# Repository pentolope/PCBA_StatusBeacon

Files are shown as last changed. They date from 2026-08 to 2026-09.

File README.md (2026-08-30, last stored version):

# Status Beacon Controller

A small USB-powered status beacon board: a microcontroller, one pushbutton, at least eight individually controllable RGB LEDs, and a small programming/debug connector.

`PCBA_StatusBeacon` is the benchmark's Status Beacon Controller: a small, USB-powered board carrying a microcontroller, one pushbutton, at least eight individually controllable RGB LEDs, and a small programming/debug connector. The brief fixes the function, the power source, the single pushbutton, a floor of at least eight individually controllable RGB LEDs, the exposure of a small programming/debug connector, and the qualitative goals of being inexpensive and easy to assemble; it also states a preference for a two-layer board unless there is a compelling reason not to. Everything else is deliberately unfixed — the brief explicitly hands the MCU, the LED technology, the exact board shape, and the connector family to the design agent, and it names no form for either connector. This is a detail-1 brief, so nearly all architecture, part selection, rail design, mechanical definition and stackup detail are left to the design agent, and this repository intentionally records those as open decisions rather than pre-answering them.

> **This board has not been designed.** There is no schematic, no layout and no
> part selection here — only the brief, a reading of the brief, and the
> scaffolding a design run needs. That is the intended state of this repository,
> not a gap in it.

## What the brief fixes, and what it leaves open

The brief pins down 13 requirements and deliberately leaves
16 decisions to whoever designs the board. The `Source` column says
which is which: `brief` is quoted from [BRIEF.md](BRIEF.md), `metadata` comes
from the benchmark catalogue, and `open` means the brief does not fix it.

| Aspect | Value | Source |
|---|---|---|
| Category | simple-digital | metadata |
| Difficulty | 1 of 5 | metadata |
| Brief detail | 1 of 5 (low-detail brief; most architecture left open) | metadata |
| Likely layer count | 2 | metadata |
| Primary stressors | basic component selection, simple placement/routing, LED current limiting, connector access | metadata |
| Function and power source | A small USB-powered status beacon board | brief |
| Controller | A microcontroller (specific device not named by the brief) | brief |
| User input | One pushbutton | brief |
| Indicators | At least eight individually controllable RGB LEDs (a floor, with no upper bound stated) | brief |
| Programming/debug access | A small programming/debug connector must be exposed; the brief names no family, form or pinout | brief |
| Cost and assembly posture | Inexpensive and easy to assemble | brief |
| Layer count preference | Two layers preferred, deviation allowed only with a compelling reason | brief |
| MCU, LED technology, board shape, connector family | Explicitly delegated to the design agent by the brief | brief |
| Status of stated requirements | Stated requirements are authoritative; open choices are to be decided and documented, not invented into requirements | brief |
| Rails, regulation, and power budget | Not fixed by the brief — design agent's choice | open |

The full split, with the verbatim brief text substantiating every fixed
requirement, is in [board/requirements.md](board/requirements.md) and
machine-readably in [board/requirements.json](board/requirements.json).

**Missing details are design freedom, not permission to fabricate unstated user
requirements.** A choice the brief left open is recorded as a decision, with its
reasoning — never promoted into a requirement.

## Benchmark position

| | |
|---|---|
| Benchmark id | 1 of 32 |
| Category | simple-digital |
| Difficulty | 1 / 5 |
| Brief detail | 1 / 5 |
| Likely layer count | 2 |
| Primary stressors | basic component selection, simple placement/routing, LED current limiting, connector access |

At difficulty 1/5 and detail 1/5 in the `simple-digital` category, this board tests whether a design agent can execute competently with almost no specification handed to it — the metadata's stressors are basic component selection, simple placement/routing, LED current limiting, and connector access. The interesting question is not whether the circuit is hard, but whether the agent makes and justifies its own choices (MCU, LED technology, shape, connector family) instead of fabricating requirements the brief never stated. Two of those stressors — LED current limiting and connector access — are where the missing detail bites hardest: with no brightness, current, environment or mechanical context stated, the per-LED current, the total the board draws from USB with the whole array lit, and the physical usability of the connectors all have to be derived and shown rather than asserted.

This repository is one of thirty-two. The suite, the protocol and the results
live in [PCBA_AutoDesignAndTest_Bench](https://github.com/pentolope/PCBA_AutoDesignAndTest_Bench).

## Repository layout

| Path | Contents |
|---|---|
| `BRIEF.md` | the supplied brief — authoritative, preserved byte for byte, never edited |
| `board/requirements.md` | what the brief fixes, what it leaves open, and where decisions get recorded |
| `board/requirements.json` | the same split, machine-readable, each fixed requirement bound to brief text |
| `board/manifest.template.json` | the toolkit's minimum manifest, pre-filled for this board |
| `board/toolchain.json` | where this board's build finds KiCad and the router |
| `benchmark/metadata.json` | the supplied catalogue entry — category, difficulty, detail, stressors |
| `docs/architecture.md` | the decisions this board must make, as questions, unanswered |
| `docs/sources.md` | the classes of evidence the design will have to cite |
| `docs/status.md` | what exists, what does not, and what is deliberately absent |
| `candidates/` | disposable search output, ignored by Git |
| `.claude/skills/` | the accountability-review skill [CLAUDE.md](CLAUDE.md) requires before a push |
| `tooling/PCBA_AutoDesignAndTest` | the shared verification/routing/release toolkit, as a pinned submodule |

## Getting the repository

The toolkit is a submodule and carries KiCad Routing Tools as a submodule of its
own, so clone recursively:

```bash
git clone --recursive https://github.com/pentolope/PCBA_StatusBeacon.git
```

```bash
git submodule update --init --recursive
```

## Designing the board

Generic verification, routing and release logic is **not** written here. It is
consumed from `tooling/PCBA_AutoDesignAndTest`, which is board-agnostic by
construction and must stay that way; this repository owns the board and nothing
else. Start from
[the toolkit's onboarding guide](tooling/PCBA_AutoDesignAndTest/examples/onboarding.md),
and see [CLAUDE.md](CLAUDE.md) for the rules a design run works under.

```bash
python3 tooling/PCBA_AutoDesignAndTest/run.py preflight
```

## Brief integrity

`BRIEF.md` SHA-256 `57889bbb86eda40bff9fa7fda22a93a18370e8318bfdb673a84f301cc4c06788`

Every quotation in `board/requirements.json` is bound to those exact bytes. If
the brief ever changes, the bindings are stale by construction — which is the
point of recording the digest.

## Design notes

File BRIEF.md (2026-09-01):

# PCBA_StatusBeacon — Status Beacon Controller
## Design brief

Design a small USB-powered status beacon board with a microcontroller, one pushbutton, and at least eight individually controllable RGB LEDs. It should be inexpensive, easy to assemble, and expose a small programming/debug connector. Choose the MCU, LED technology, exact board shape, and connector family yourself. Prefer a two-layer board unless there is a compelling reason not to.

## Functional requirements

- Each LED's red, green and blue elements shall be settable independently, and updating one LED shall not disturb the others.
- The pushbutton shall be the only user control; press and release shall reach the MCU as single debounced events.
- On USB power alone, with no host software, the board shall reach a defined LED state.

## LED array and drive

- Drive signals shall meet the receiving device's input thresholds across the operating range, including any rail difference.
- Peak LED current shall be bounded by the drive circuit or by one documented firmware limit, shall repeat across assemblies without rework, and shall not produce visible flicker.

## Power and current budget

- Worst-case current, all LEDs at maximum with the MCU active, shall be calculated, measured at bring-up, and within what the board may draw from the port it declares.
- Operation shall hold over the full VBUS range the connector and cable permit at that load, with input capacitance inside the USB inrush limit and any lower rail within its temperature limits.

## Interfaces and debug connector

- The USB receptacle shall be mechanically retained so mating forces are not carried by signal joints alone; a Type-C sink shall present its class's CC terminations.
- The debug connector shall program and halt the chosen MCU in circuit on a blank or bricked device, be polarised or pin-1 marked, and be unnecessary in normal use.

## Mechanical, placement and assembly

- Two copper layers unless a documented constraint forces more, with continuous ground reference under the MCU and LED clock and data routing.
- LED positions shall form a deliberate, repeatable arrangement, and the button shall be operable without touching the LEDs or connector.
- Assembly shall need no more than stencil print, single-side placement and one reflow pass.

## Protection and bring-up

- Exposed USB contacts and the pushbutton shall have ESD protection to board ground; hot-plug shall not damage or latch up the board, and no signal shall be driven into an unpowered device.
- VBUS, ground and every LED drive signal shall be probeable when assembled, and total supply current measurable without cutting a trace.

## Open choices

- MCU, LED technology and drive topology, and per-channel resolution: on/off, or a stated modulation depth.
- USB receptacle and debug connector families; board outline and LED geometry; whether the board enumerates or takes power only.

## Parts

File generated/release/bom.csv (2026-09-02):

Quantity | Designator | Comment | Footprint | LCSC Part #
2 | C1,C17 | 4.7uF | Capacitor_SMD:C_0805_2012Metric | C1779
15 | C2,C3,C4,C5,C6,C7,C8,C9,C10,C11,C12,C13,C14,C15,C16 | 100nF | Capacitor_SMD:C_0402_1005Metric | C1525
12 | D1,D2,D3,D4,D5,D6,D7,D8,D9,D10,D11,D12 | WS2812B-V5/W | LED_SMD:LED_WS2812B_PLCC4_5.0x5.0mm_P3.2mm | C2874885
4 | D13,D14,D15,D16 | TPD1E10B06DPYR | StatusBeacon:TI_X1SON-2_1.0x0.6mm_P0.65mm | C48260
1 | J1 | USB_C_16P | StatusBeacon:USB_C_Receptacle_HRO_TYPE-C-31-M-12_LCSC | C165948
2 | R1,R2 | 5.1k | Resistor_SMD:R_0402_1005Metric | C25905
1 | R4 | 33R | Resistor_SMD:R_0402_1005Metric | C25105
1 | R5 | 1k | Resistor_SMD:R_0402_1005Metric | C11702
1 | R6 | 10k | Resistor_SMD:R_0402_1005Metric | C25744
1 | SW1 | K2-1187SQ-A4SW-06 | Button_Switch_SMD:SW_SPST_SKQG_WithoutStem | C92584
1 | U1 | PY32F003F18P6TU | Package_SO:TSSOP-20_4.4x6.5mm_P0.65mm | C5379864
1 | U2 | ME6211C50M5G-N | Package_TO_SOT_SMD:SOT-23-5 | C236670

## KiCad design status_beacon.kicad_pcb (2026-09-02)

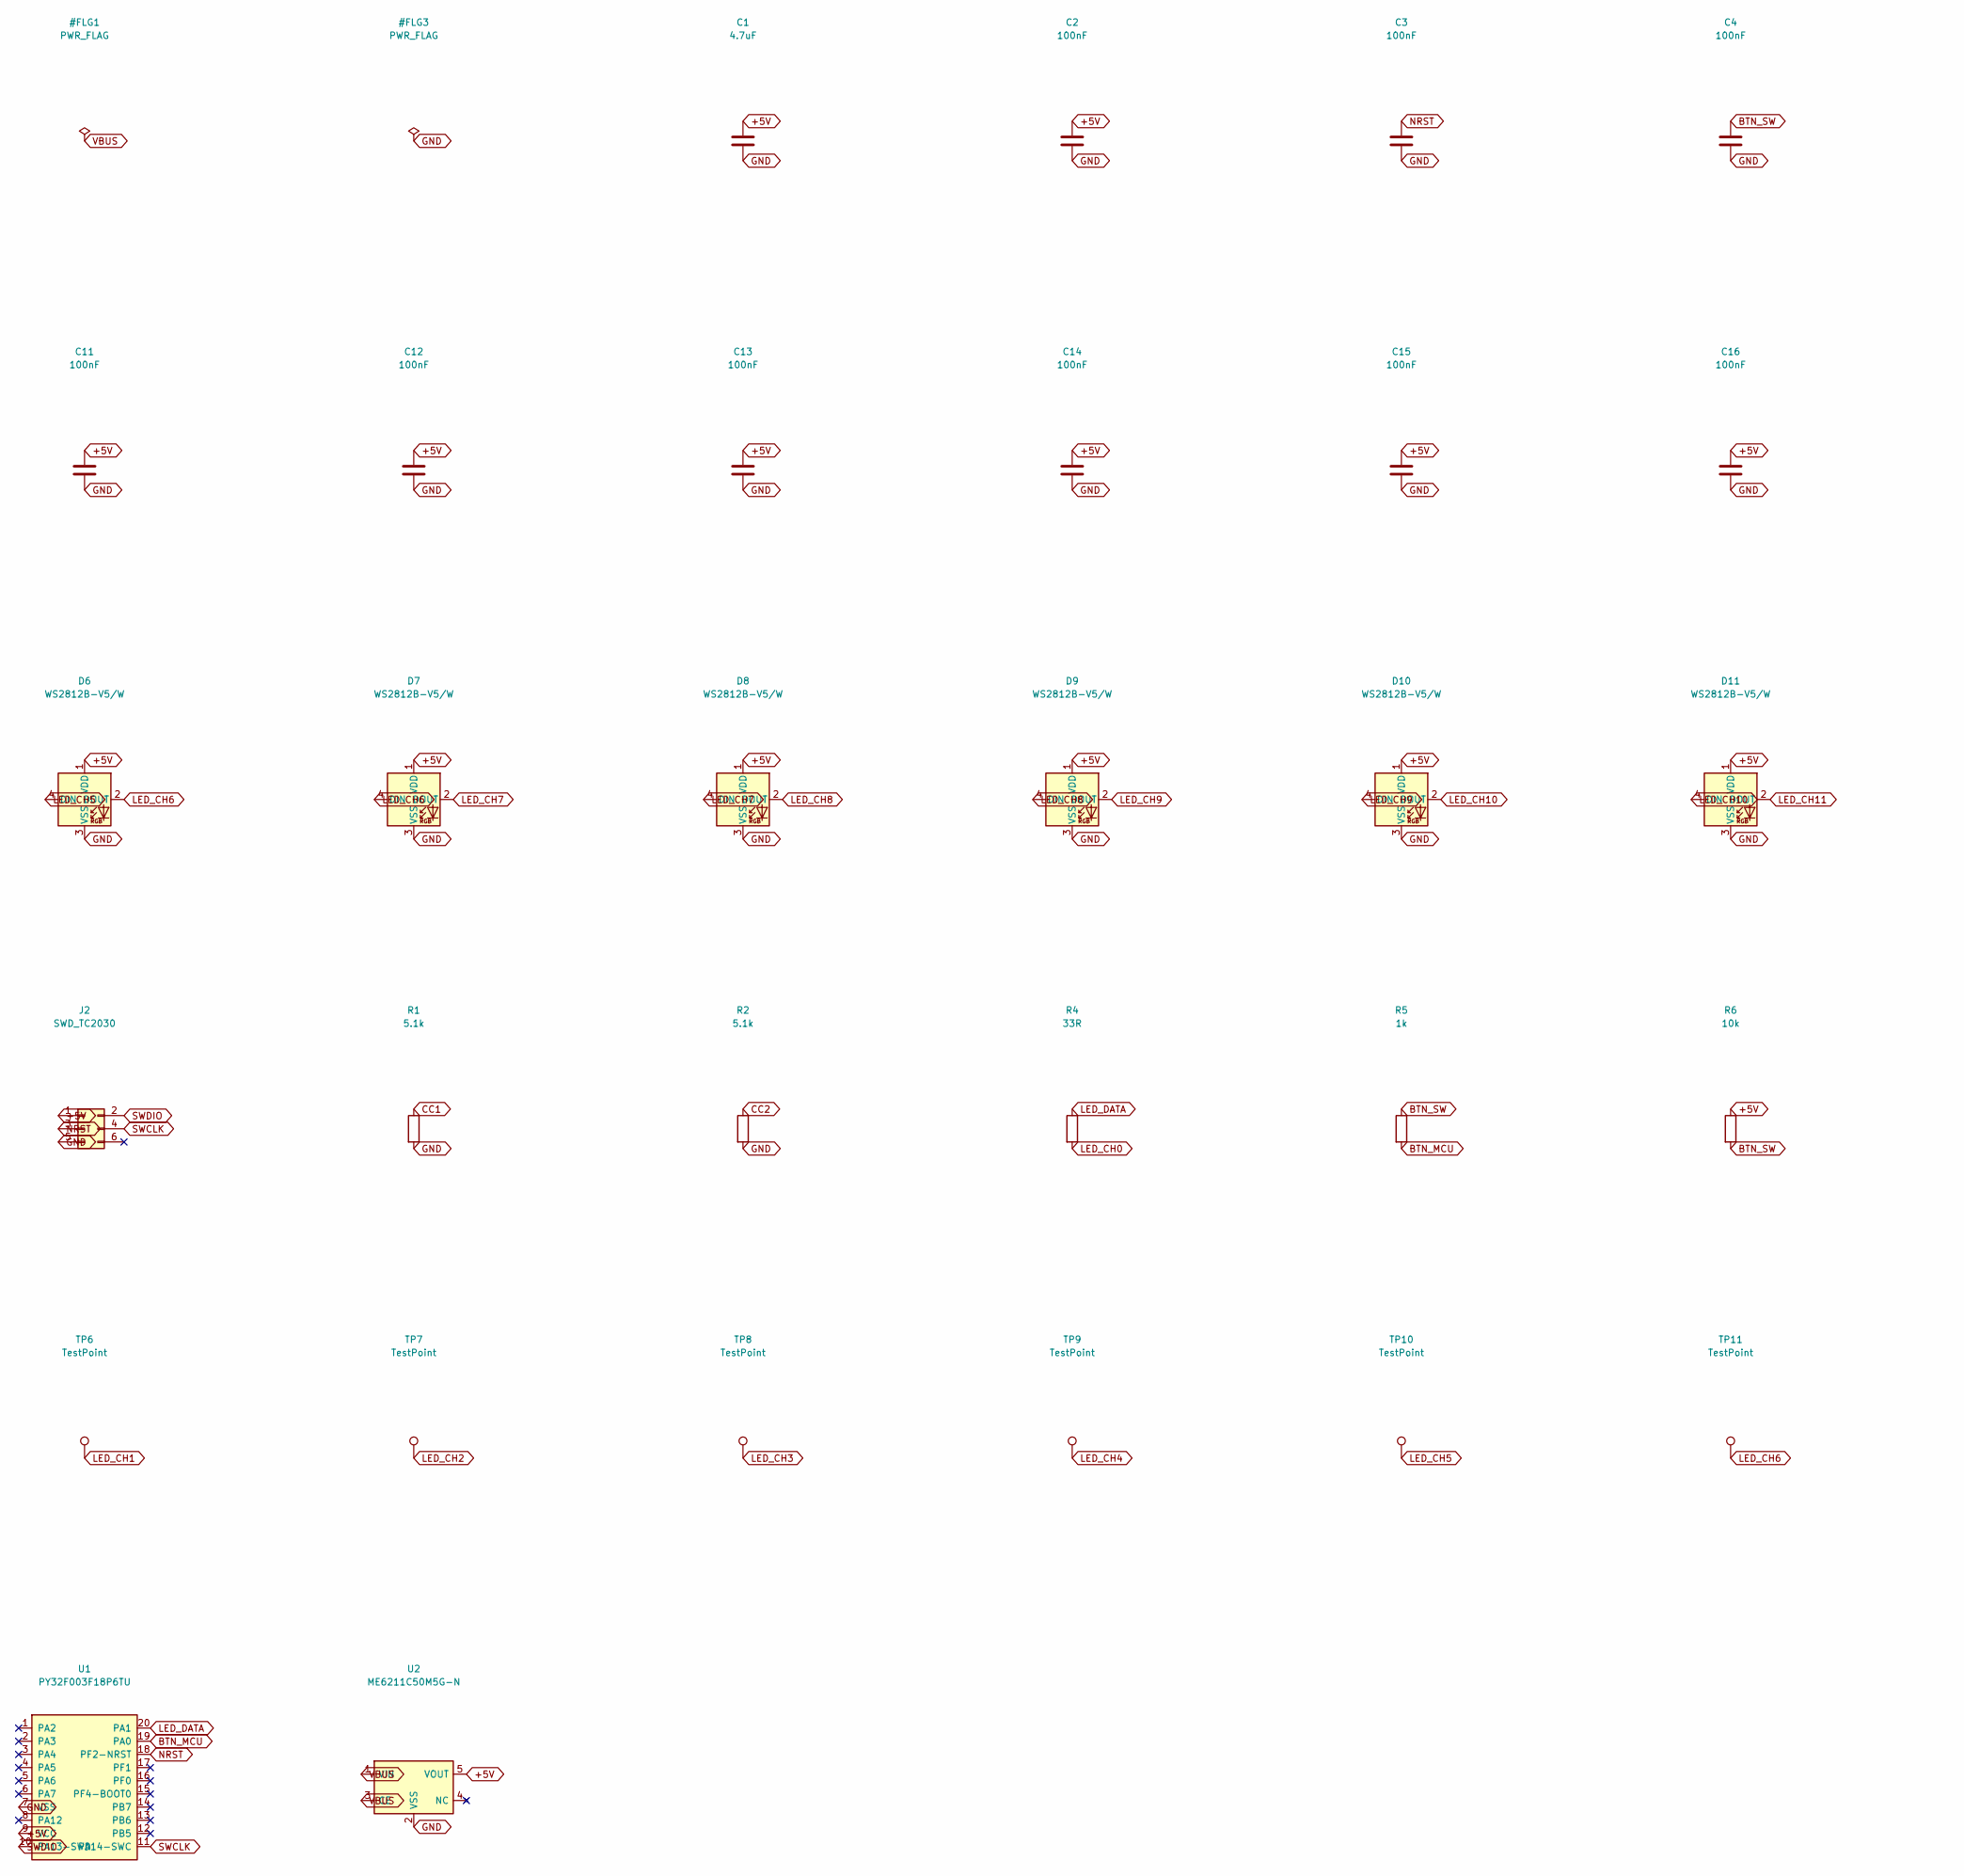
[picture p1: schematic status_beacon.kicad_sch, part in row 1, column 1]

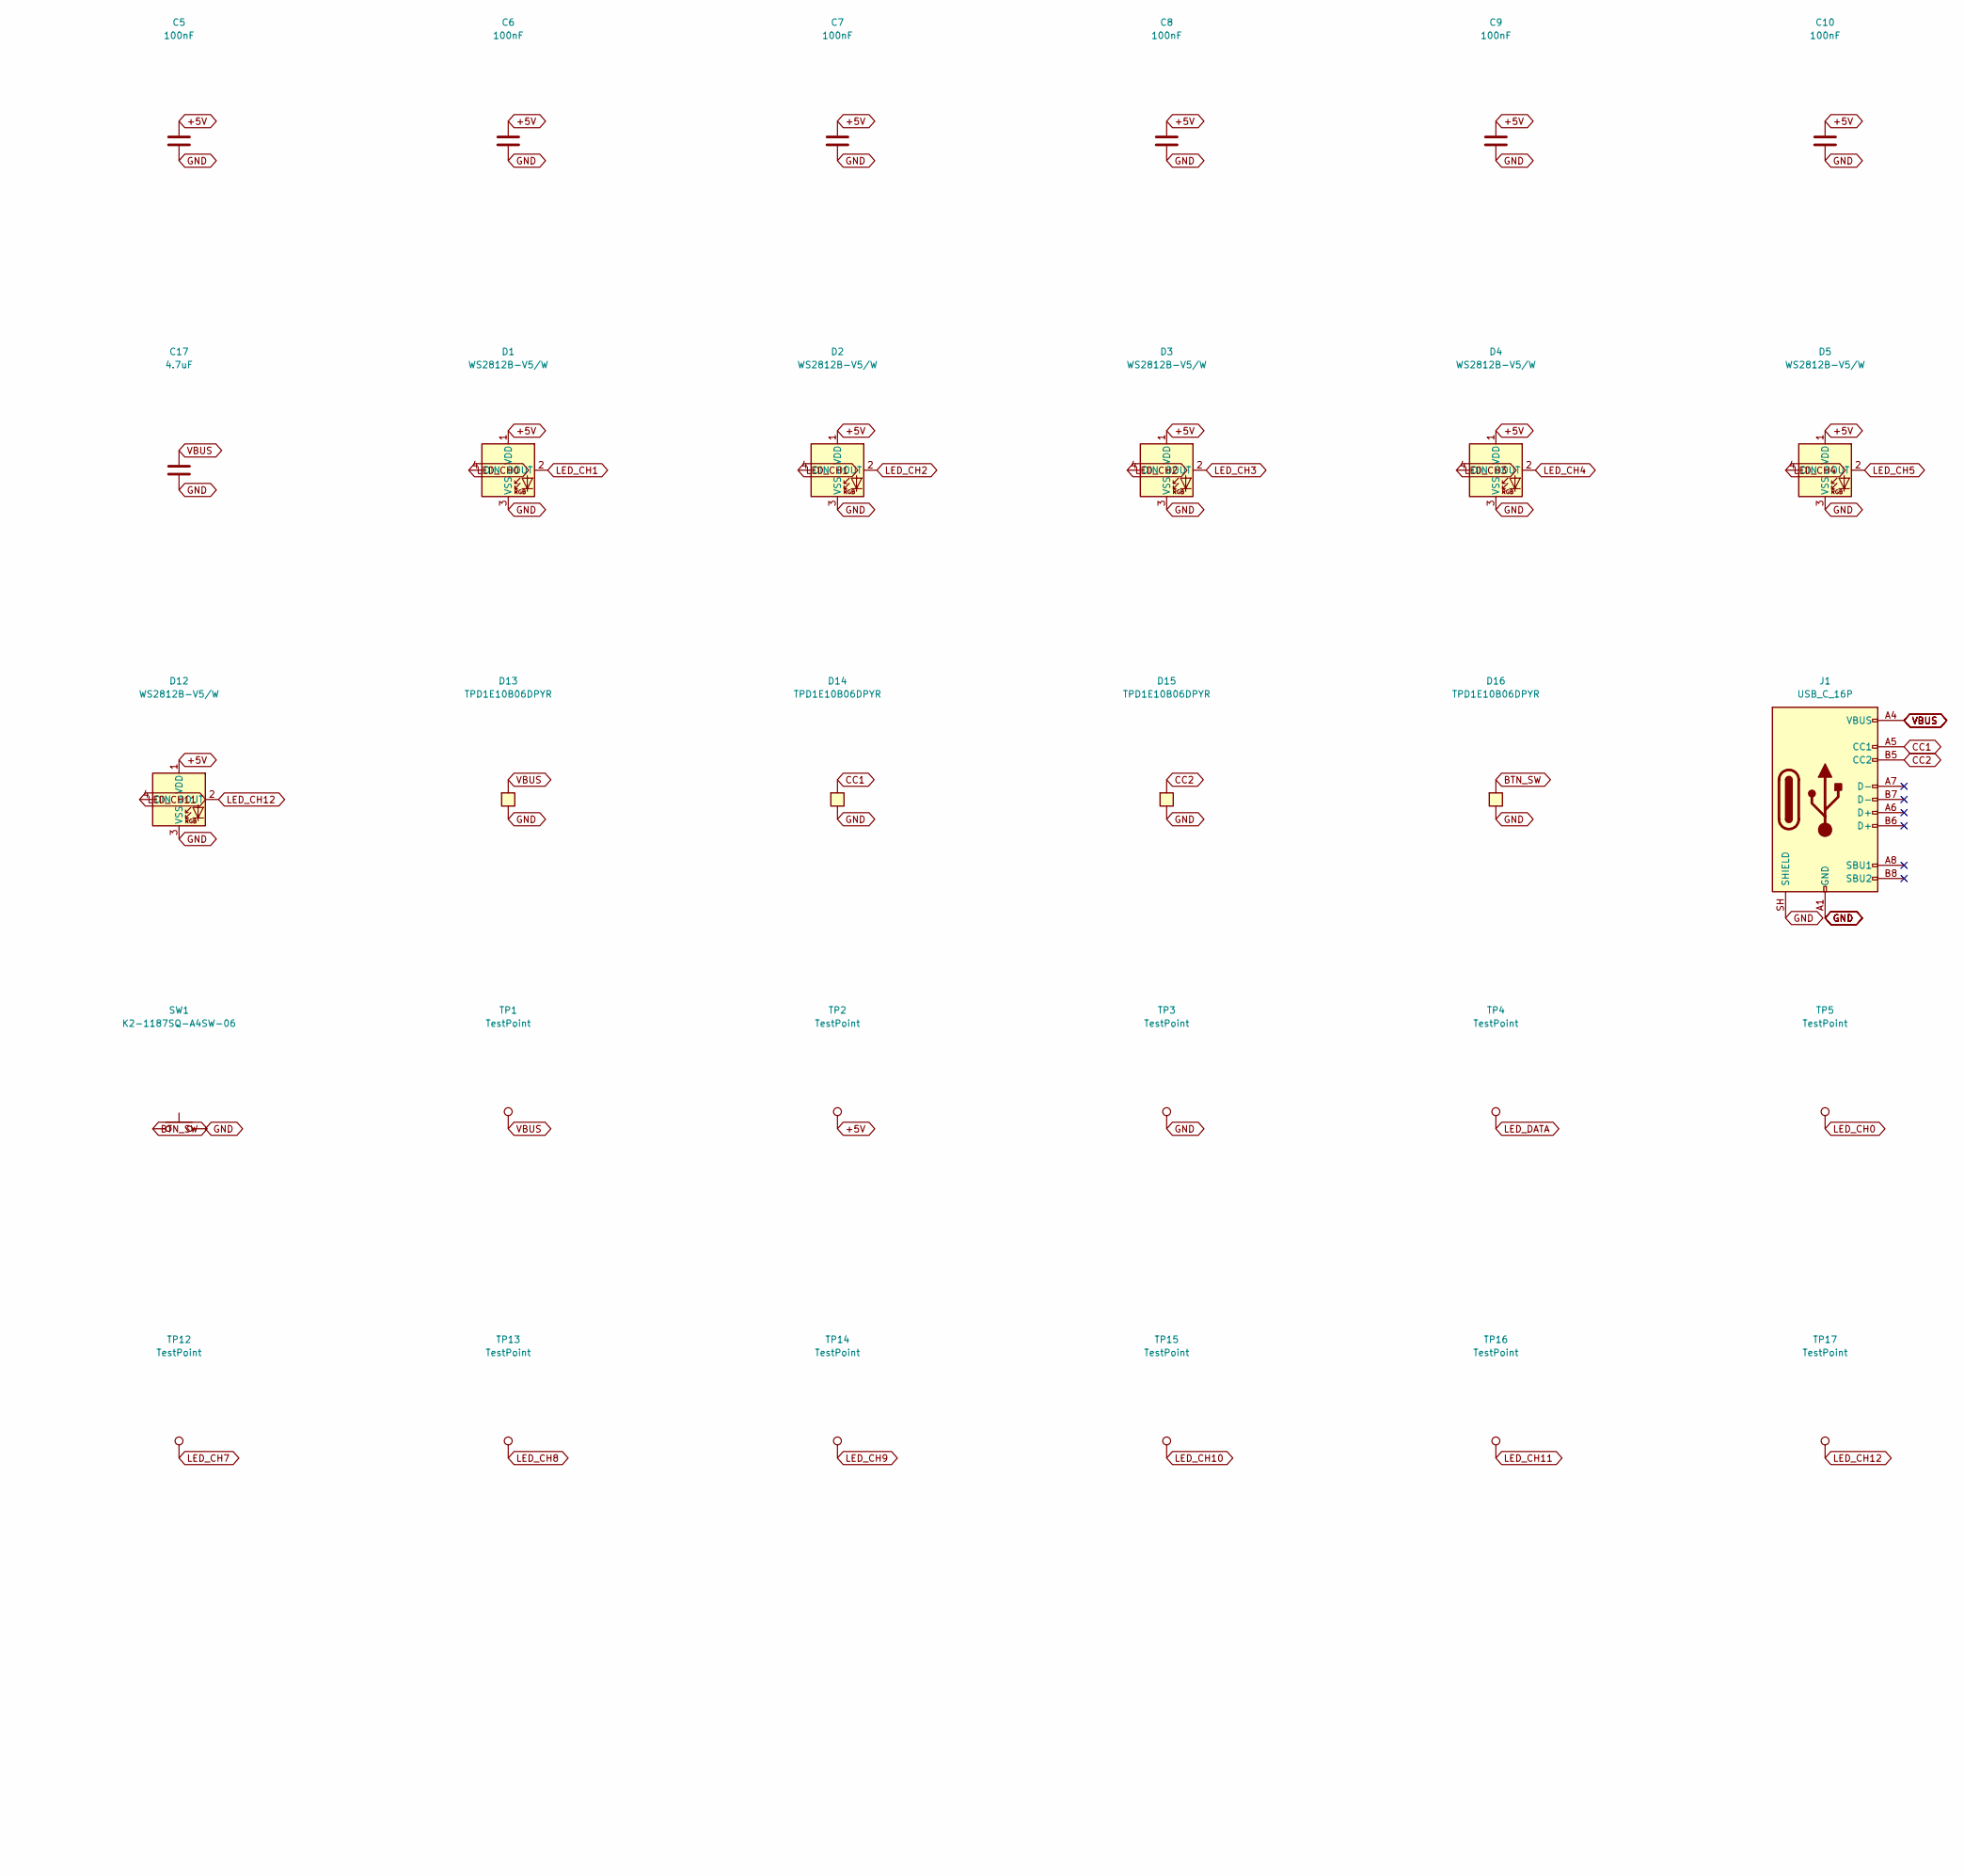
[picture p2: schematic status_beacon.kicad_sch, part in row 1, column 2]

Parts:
C1, C17: 4.7uF; C_0805_2012Metric; LCSC C1779
C2, C3, C4, C5, C6, C7, C8, C9, C10, C11, C12, C13, C14, C15, C16: 100nF; C_0402_1005Metric; LCSC C1525
D1, D2, D3, D4, D5, D6, D7, D8, D9, D10, D11, D12: WS2812B-V5/W; LED_WS2812B_PLCC4_5.0x5.0mm_P3.2mm; MPN WS2812B-V5/W; LCSC C2874885
D13, D14, D15, D16: TPD1E10B06DPYR; TI_X1SON-2_1.0x0.6mm_P0.65mm; MPN TPD1E10B06DPYR; LCSC C48260
J1: USB_C_16P; USB_C_Receptacle_HRO_TYPE-C-31-M-12_LCSC; MPN TYPE-C-31-M-12; LCSC C165948
J2: SWD_TC2030; Tag-Connect_TC2030-IDC-NL_2x03_P1.27mm_Vertical
R1, R2: 5.1k; R_0402_1005Metric; LCSC C25905
R4: 33R; R_0402_1005Metric; LCSC C25105
R5: 1k; R_0402_1005Metric; LCSC C11702
R6: 10k; R_0402_1005Metric; LCSC C25744
SW1: K2-1187SQ-A4SW-06; SW_SPST_SKQG_WithoutStem; MPN K2-1187SQ-A4SW-06; LCSC C92584
TP1, TP2, TP3, TP4, TP5, TP6, TP7, TP8, TP9, TP10, TP11, TP12, TP13, TP14, TP15, TP16, TP17: TestPoint; TestPoint_Pad_D1.0mm
U1: PY32F003F18P6TU; TSSOP-20_4.4x6.5mm_P0.65mm; MPN PY32F003F18P6TU; LCSC C5379864
U2: ME6211C50M5G-N; SOT-23-5; MPN ME6211C50M5G-N; LCSC C236670

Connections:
+5V: C1.1, C2.1, C5.1, C6.1, C7.1, C8.1, C9.1, C10.1, C11.1, C12.1, C13.1, C14.1, C15.1, C16.1, D1.1 (VDD), D2.1 (VDD), D3.1 (VDD), D4.1 (VDD), D5.1 (VDD), D6.1 (VDD), D7.1 (VDD), D8.1 (VDD), D9.1 (VDD), D10.1 (VDD), D11.1 (VDD), D12.1 (VDD), J2.1, R6.1, TP2.1, U1.9 (VCC), U2.5 (VOUT)
BTN_MCU: R5.2, U1.19 (PA0)
BTN_SW: C4.1, D16.2 (A2), R5.1, R6.2, SW1.1
CC1: D14.2 (A2), J1.A5 (CC1), R1.1
CC2: D15.2 (A2), J1.B5 (CC2), R2.1
GND: C1.2, C2.2, C3.2, C4.2, C5.2, C6.2, C7.2, C8.2, C9.2, C10.2, C11.2, C12.2, C13.2, C14.2, C15.2, C16.2, C17.2, D1.3 (VSS), D2.3 (VSS), D3.3 (VSS), D4.3 (VSS), D5.3 (VSS), D6.3 (VSS), D7.3 (VSS), D8.3 (VSS), D9.3 (VSS), D10.3 (VSS), D11.3 (VSS), D12.3 (VSS), D13.1 (A1), D14.1 (A1), D15.1 (A1), D16.1 (A1), J1.A1 (GND), J1.A12 (GND), J1.B1 (GND), J1.B12 (GND), J1.SH (SHIELD), J2.5, R1.2, R2.2, SW1.2, TP3.1, U1.7 (VSS), U2.2 (VSS)
LED_CH0: D1.4 (DIN), R4.2, TP5.1
LED_CH1: D1.2 (DOUT), D2.4 (DIN), TP6.1
LED_CH2: D2.2 (DOUT), D3.4 (DIN), TP7.1
LED_CH3: D3.2 (DOUT), D4.4 (DIN), TP8.1
LED_CH4: D4.2 (DOUT), D5.4 (DIN), TP9.1
LED_CH5: D5.2 (DOUT), D6.4 (DIN), TP10.1
LED_CH6: D6.2 (DOUT), D7.4 (DIN), TP11.1
LED_CH7: D7.2 (DOUT), D8.4 (DIN), TP12.1
LED_CH8: D8.2 (DOUT), D9.4 (DIN), TP13.1
LED_CH9: D9.2 (DOUT), D10.4 (DIN), TP14.1
LED_CH10: D10.2 (DOUT), D11.4 (DIN), TP15.1
LED_CH11: D11.2 (DOUT), D12.4 (DIN), TP16.1
LED_CH12: D12.2 (DOUT), TP17.1
LED_DATA: R4.1, TP4.1, U1.20 (PA1)
NRST: C3.1, J2.3, U1.18 (PF2-NRST)
SWCLK: J2.4, U1.11 (PA14-SWC)
SWDIO: J2.2, U1.10 (PA13-SWD)
VBUS: C17.1, D13.2 (A2), J1.A4 (VBUS), J1.A9 (VBUS), J1.B4 (VBUS), J1.B9 (VBUS), TP1.1, U2.1 (VIN), U2.3 (CE)

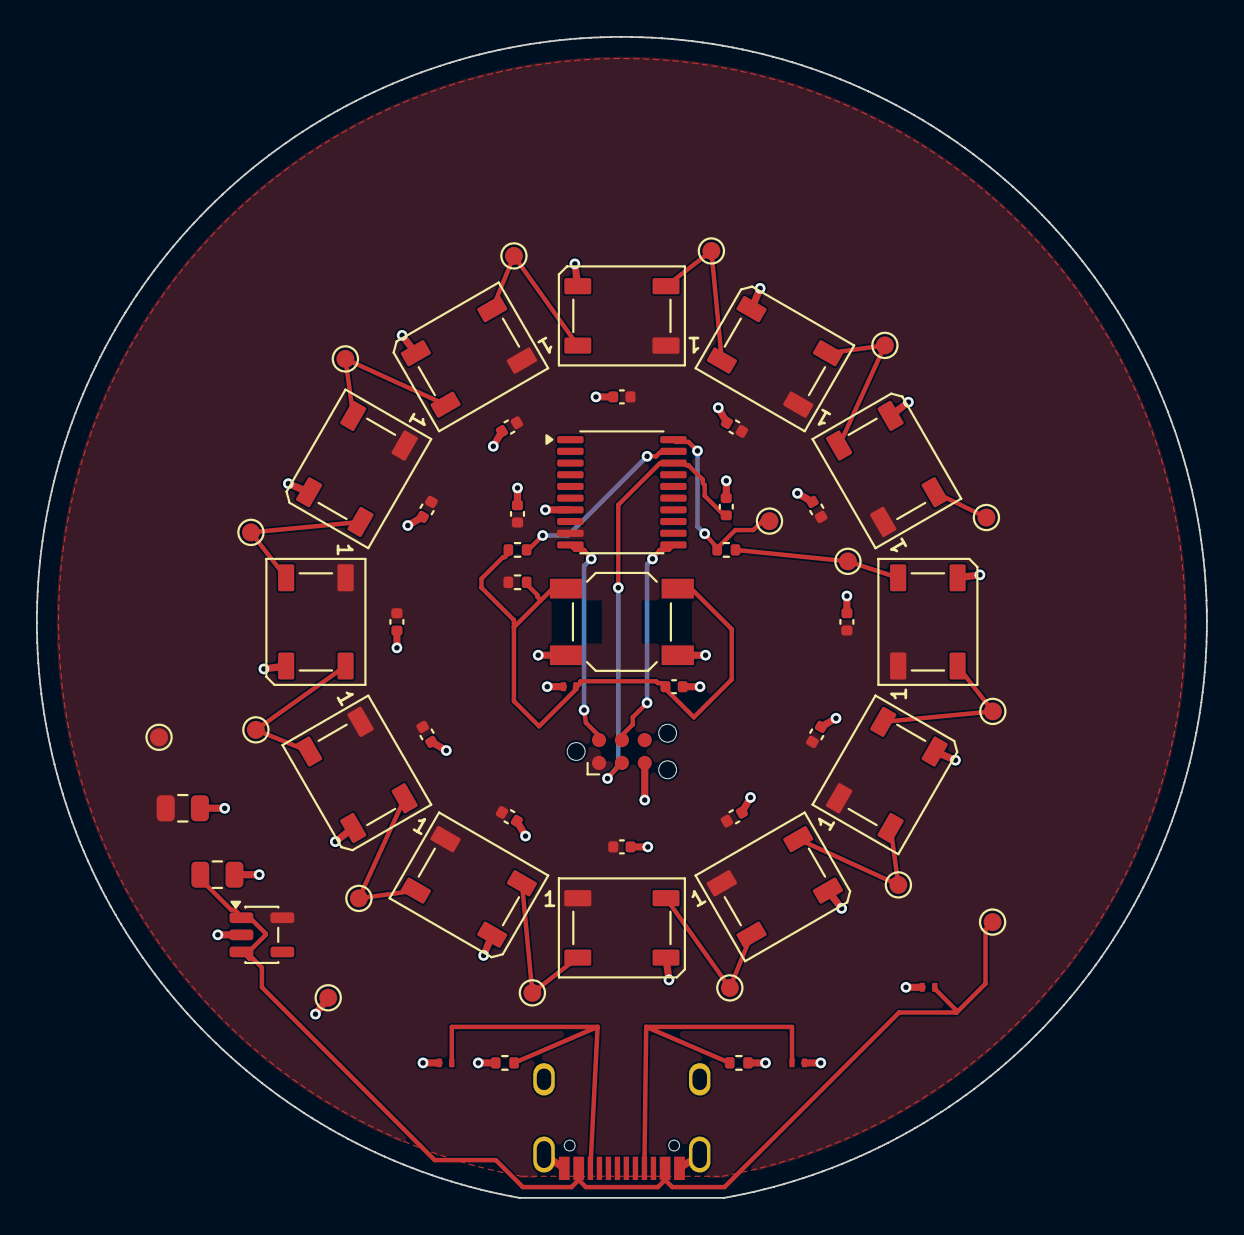
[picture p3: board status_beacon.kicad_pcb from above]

Board: 2 copper layers, 65.0 x 64.5 mm, 60 parts (0 on the bottom side), 24 nets.

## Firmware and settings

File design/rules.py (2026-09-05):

from __future__ import annotations

import json
import os
import re
import sys

from . import netlist

REPO_ROOT = os.path.dirname(os.path.dirname(os.path.abspath(__file__)))
PARAMETERS_PATH = os.path.join(REPO_ROOT, "components", "parameters.json")
TOOLKIT_ROOT = os.path.join(REPO_ROOT, "tooling", "PCBA_AutoDesignAndTest")
FOOTPRINT_ROOT = "/usr/share/kicad/footprints"

if TOOLKIT_ROOT not in sys.path:
    sys.path.insert(0, TOOLKIT_ROOT)

from pcbqa import claim  # noqa: E402

DIRECT = "direct"
ASSUMED = "assumed"
DERIVED = "derived"

CAPACITOR_TOLERANCE = 0.20

SERIES_PASSIVE_PREFIXES = ("R", "L", "FB")

EXPOSED_CONTACT_REFERENCE = "J1"

PROBE_REQUIRED_NETS = ("VBUS", "GND", "+5V", "LED_DATA")

DEBUG_CONTRACT = {
    "J2.1": "+5V",
    "J2.2": "SWDIO",
    "J2.3": "NRST",
    "J2.4": "SWCLK",
    "J2.5": "GND",
}


class Quantity:
    __slots__ = ("value", "basis", "documents")

    def __init__(self, value, basis, documents=()):
        self.value = value
        self.basis = basis
        self.documents = tuple(documents)

    @property
    def known(self):
        return self.value is not None


UNKNOWN = Quantity(None, None)


def load_parameters():
    with open(PARAMETERS_PATH, "r", encoding="utf-8") as handle:
        return json.load(handle)


def _quantity(record, supply_v=None):
    if not isinstance(record, dict):
        return UNKNOWN
    if record.get("knowledge") == "unknown":
        return UNKNOWN
    documents = (record["document"],) if record.get("document") else ()
    basis = record.get("basis", ASSUMED)
    if "factor_of_supply" in record:
        if supply_v is None:
            return UNKNOWN
        return Quantity(record["factor_of_supply"] * supply_v, basis,
                        documents)
    if "offset_from_supply" in record:
        if supply_v is None:
            return UNKNOWN
        return Quantity(record["offset_from_supply"] + supply_v, basis,
                        documents)
    if "value" in record:
        return Quantity(record["value"], basis, documents)
    return UNKNOWN


def _combine(*quantities):
    basis = DIRECT
    documents = []
    for quantity in quantities:
        if not quantity.known:
            return None, None, ()
        if quantity.basis == ASSUMED:
            basis = ASSUMED
        elif quantity.basis == DERIVED and basis != ASSUMED:
            basis = DERIVED
        documents.extend(quantity.documents)
    return True, basis, tuple(sorted(set(documents)))


def _mpn(reference):
    part = netlist.PARTS[reference]
    return part["mpn"]


def _part_parameters(parameters, reference):
    return parameters["parts"].get(_mpn(reference))


def _pin_map():
    mapping = {}
    for net_name, pin_refs in netlist.NETS.items():
        for pin_ref in pin_refs:
            mapping[pin_ref] = net_name
    return mapping


def _net_pins():
    return {name: list(pins) for name, pins in netlist.NETS.items()}


EVIDENCE_CLASSES = {
    DIRECT: "datasheet-behavioral",
    ASSUMED: "assumed-behavioral",
    DERIVED: "design-source",
}


def _evidence(basis, documents, assumptions=(), omissions=()):
    provenance = {
        "source": "components/parameters.json",
        "documents": list(documents),
    }
    return claim.evidence(
        "device_electrical", EVIDENCE_CLASSES.get(basis, "design-source"),
        provenance, assumptions=list(assumptions),
        omitted_contributions=list(omissions))


def _claim(identity, units, significance, value, basis, documents,
           requirement, knowledge, scope_level="net", assumptions=(),
           omissions=()):
    if value is None:
        return claim.claim(
            scope_level, identity, units, claim.UNKNOWN, {},
            _evidence(basis, documents, assumptions, omissions),
            significance, None, requirement)
    knowledge_basis = None
    if knowledge != claim.EXACT:
        knowledge_basis = claim.knowledge_basis(
            basis, "datasheet_limit" if basis == DIRECT else basis)
    quantity = {"value": value}
    return claim.claim(
        scope_level, identity, units, knowledge, quantity,
        _evidence(basis, documents, assumptions, omissions),
        significance, knowledge_basis, requirement)


def _requirement(name, op, value):
    return claim.requirement(name, "BRIEF.md", {"op": op, "value": value})


def _series_graph():
    graph = {}
    for reference, part in netlist.PARTS.items():
        prefix = reference.rstrip("0123456789")
        if prefix not in SERIES_PASSIVE_PREFIXES:
            continue
        graph.setdefault(reference + ".1", set()).add(reference + ".2")
        graph.setdefault(reference + ".2", set()).add(reference + ".1")
    return graph


def _reachable_nets(start_net, pin_map, net_pins):
    graph = _series_graph()
    seen = {start_net}
    frontier = [start_net]
    series_refs = []
    while frontier:
        net_name = frontier.pop()
        for pin_ref in net_pins.get(net_name, ()):
            for other in graph.get(pin_ref, ()):
                other_net = pin_map.get(other)
                if other_net and other_net not in seen:
                    seen.add(other_net)
                    series_refs.append(pin_ref.split(".")[0])
                    frontier.append(other_net)
    return seen, series_refs


def logic_links(parameters):
    pin_map = _pin_map()
    net_pins = _net_pins()
    links = []
    for reference, part in sorted(netlist.PARTS.items()):
        spec = _part_parameters(parameters, reference)
        if not spec:
            continue
        for pin_number, output in sorted(spec.get("digital_outputs",
                                                  {}).items()):
            driver_pin = "%s.%s" % (reference, pin_number)
            driver_net = pin_map.get(driver_pin)
            if driver_net is None:
                continue
            nets, series_refs = _reachable_nets(driver_net, pin_map, net_pins)
            receivers = []
            for net_name in sorted(nets):
                for pin_ref in net_pins.get(net_name, ()):
                    if pin_ref == driver_pin:
                        continue
                    other_ref, _, other_pin = pin_ref.partition(".")
                    other_spec = _part_parameters(parameters, other_ref)
                    if not other_spec:
                        continue
                    entry = other_spec.get("digital_inputs", {}).get(other_pin)
                    if entry is not None:
                        receivers.append((pin_ref, other_ref, entry))
            if receivers:
                links.append((driver_pin, reference, output, driver_net,
                              receivers, series_refs))
    return links


def _supply_range(reference, pin_number, spec, parameters):
    pin_map = _pin_map()
    supply_pin = spec.get("digital_outputs", {}).get(pin_number, {}).get(
        "reference_supply_pin")
    if supply_pin is None:
        supply_pin = spec.get("digital_inputs", {}).get(pin_number, {}).get(
            "reference_supply_pin")
    if supply_pin is None:
        supply_pins = spec.get("supply_pins") or []
        supply_pin = supply_pins[0] if supply_pins else None
    if supply_pin is None:
        return None
    rail = pin_map.get("%s.%s" % (reference, supply_pin))
    return netlist.RAILS.get(rail)


def _series_resistance(series_refs):
    total = 0.0
    for reference in series_refs:
        value = netlist.PARTS[reference]["value"]
        match = re.match(r"^([\d.]+)R?$", value.replace("k", "e3"))
        if not match:
            return None
        total += float(match.group(1))
    return total


def evaluate_logic_levels(parameters):
    results = []
    for (driver_pin, driver_ref, output, driver_net, receivers,
         series_refs) in logic_links(parameters):
        driver_rail = _supply_range(
            driver_ref, driver_pin.split(".")[1],
            _part_parameters(parameters, driver_ref), parameters)
        resistance = _series_resistance(series_refs)
        for receiver_pin, receiver_ref, entry in receivers:
            identity = "%s->%s" % (driver_pin, receiver_pin)
            receiver_rail = _supply_range(
                receiver_ref, receiver_pin.split(".")[1],
                _part_parameters(parameters, receiver_ref), parameters)
            margin, basis, documents, assumptions = _high_level_margin(
                output, entry, driver_rail, receiver_rail, resistance)
            results.append({
                "id": "logic_high_margin",
                "identity": identity,
                "claim": _claim(
                    identity, "V", "logic_high_noise_margin", margin, basis,
                    documents, _requirement(
                        "drive_meets_receiver_threshold", ">=", 0.0),
                    claim.LOWER_BOUND if margin is not None else claim.UNKNOWN,
                    assumptions=assumptions),
            })
    return results


def _high_level_margin(output, entry, driver_rail, receiver_rail, resistance):
    if driver_rail is None or receiver_rail is None:
        return None, None, (), ()
    voh_record = output.get("voh_min", {})
    vih_record = entry.get("vih_min", {})
    valid_min = voh_record.get("valid_supply_min_v")
    if valid_min is not None and driver_rail["min_v"] < valid_min:
        return None, None, (), ()
    worst = None
    basis = DIRECT
    documents = ()
    assumptions = []
    for rail_v in (receiver_rail["min_v"], receiver_rail["max_v"]):
        vih = _quantity(vih_record, rail_v)
        voh = _quantity(voh_record, driver_rail["min_v"])
        known, combined_basis, combined_documents = _combine(vih, voh)
        if not known:
            return None, None, (), ()
        drop = 0.0
        if resistance:
            current = entry.get("input_current_max_a")
            if current is None:
                assumptions.append("series_drop_omitted")
            else:
                drop = resistance * current
        margin = voh.value - drop - vih.value
        if worst is None or margin < worst:
            worst = margin
            basis = combined_basis
            documents = combined_documents
    return worst, basis, documents, tuple(sorted(set(assumptions)))


def evaluate_supply_current(parameters):
    total = 0.0
    basis = DIRECT
    documents = []
    unknown = False
    contributions = {}
    for reference in sorted(netlist.PARTS):
        spec = _part_parameters(parameters, reference)
        if not spec:
            continue
        quantity = _quantity(spec.get("supply_current_max_a", {}))
        if not quantity.known:
            unknown = True
            continue
        current = quantity.value
        if spec.get("current_scales_with_brightness_limit"):
            current *= netlist.FIRMWARE_GLOBAL_BRIGHTNESS_LIMIT
        total += current
        contributions[reference] = current
        if quantity.basis == ASSUMED:
            basis = ASSUMED
        documents.extend(quantity.documents)
    value = None if unknown else total
    return {
        "id": "supply_current_budget",
        "identity": "board_vbus_current",
        "contributions": contributions,
        "claim": _claim(
            "board_vbus_current", "A", "port_current_budget", value, basis,
            tuple(sorted(set(documents))),
            _requirement("within_declared_port_budget", "<=",
                         netlist.PORT_BUDGET_A),
            claim.UPPER_BOUND if value is not None else claim.UNKNOWN,
            scope_level="board"),
    }


def _capacitance_farads(value):
    match = re.match(r"^([\d.]+)(p|n|u)F$", value)
    if not match:
        return None
    scale = {"p": 1e-12, "n": 1e-9, "u": 1e-6}[match.group(2)]
    return float(match.group(1)) * scale


def evaluate_vbus_capacitance(parameters):
    pin_map = _pin_map()
    net_pins = _net_pins()
    domain, _series = _reachable_nets("VBUS", pin_map, net_pins)
    total = 0.0
    included = {}
    for reference, part in sorted(netlist.PARTS.items()):
        if not reference.startswith("C"):
            continue
        pins = {pin_map.get("%s.1" % reference),
                pin_map.get("%s.2" % reference)}
        if not pins & domain:
            continue
        farads = _capacitance_farads(part["value"])
        if farads is None:
            return {"id": "vbus_bypass_capacitance",
                    "identity": "vbus_domain",
                    "claim": _claim(
                        "vbus_domain", "F", "usb_inrush_capacitance", None,
                        None, (), _requirement(
                            "within_usb_bypass_capacitance_limit", "<=",
                            netlist.VBUS_CAPACITANCE_LIMIT_F),
                        claim.UNKNOWN, scope_level="board")}
        included[reference] = farads
        total += farads * (1.0 + CAPACITOR_TOLERANCE)
    return {
        "id": "vbus_bypass_capacitance",
        "identity": "vbus_domain",
        "included": included,
        "claim": _claim(
            "vbus_domain", "F", "usb_inrush_capacitance", total, DERIVED, (),
            _requirement("within_usb_bypass_capacitance_limit", "<=",
                         netlist.VBUS_CAPACITANCE_LIMIT_F),
            claim.UPPER_BOUND, scope_level="board"),
    }


def evaluate_absolute_maximum(parameters):
    pin_map = _pin_map()
    results = []
    for reference in sorted(netlist.PARTS):
        spec = _part_parameters(parameters, reference)
        if not spec:
            continue
        for supply_pin in spec.get("supply_pins", []):
            rail_name = pin_map.get("%s.%s" % (reference, supply_pin))
            rail = netlist.RAILS.get(rail_name)
            if rail is None:
                continue
            identity = "%s.%s@%s" % (reference, supply_pin, rail_name)
            abs_max = _quantity(spec.get("supply", {}).get("abs_max_v", {}))
            if abs_max.known:
                margin = abs_max.value - rail["max_v"]
                knowledge = claim.LOWER_BOUND
                basis = abs_max.basis
                documents = abs_max.documents
            else:
                margin, knowledge, basis, documents = (
                    None, claim.UNKNOWN, None, ())
            results.append({
                "id": "supply_absolute_maximum_margin",
                "identity": identity,
                "claim": _claim(
                    identity, "V", "device_absolute_maximum_margin", margin,
                    basis, documents,
                    _requirement("rail_within_absolute_maximum", ">=", 0.0),
                    knowledge, scope_level="measurement"),
            })
    return results


def evaluate_source_range_coverage(parameters):
    vsafe5v_max = parameters["usb"]["vsafe5v_max_v"]
    declared_max = netlist.RAILS["VBUS"]["max_v"]
    return {
        "id": "usb_source_range_coverage",
        "identity": "vbus_declared_vs_vsafe5v",
        "claim": _claim(
            "vbus_declared_vs_vsafe5v", "V",
            "declared_range_covers_source_range",
            declared_max - vsafe5v_max, DERIVED, (),
            _requirement("covers_usb_c_vsafe5v_maximum", ">=", 0.0),
            claim.EXACT,
            scope_level="board"),
    }


def _structural_claim(identity, significance, violations, requirement_name):
    return _claim(
        identity, "count", significance, float(len(violations)), DIRECT, (),
        _requirement(requirement_name, "<=", 0.0), claim.EXACT,
        scope_level="board")


def evaluate_cc_terminations(parameters):
    pin_map = _pin_map()
    net_pins = _net_pins()
    wanted = parameters["usb"]["sink_cc_termination_ohms"]
    tolerance = parameters["usb"]["sink_cc_termination_tolerance"]
    violations = []
    for net_name in ("CC1", "CC2"):
        terminators = []
        for pin_ref in net_pins.get(net_name, ()):
            reference = pin_ref.split(".")[0]
            if not reference.startswith("R"):
                continue
            other = "%s.%s" % (
                reference, "2" if pin_ref.endswith(".1") else "1")
            if pin_map.get(other) != "GND":
                continue
            ohms = _resistance_ohms(netlist.PARTS[reference]["value"])
            terminators.append((reference, ohms))
        if len(terminators) != 1:
            violations.append((net_name, "termination_count",
                               len(terminators)))
            continue
        reference, ohms = terminators[0]
        if ohms is None or abs(ohms - wanted) > wanted * tolerance:
            violations.append((net_name, "termination_value", ohms))
    return {
        "id": "typec_sink_cc_terminations",
        "identity": "cc_terminations",
        "violations": violations,
        "claim": _structural_claim(
            "cc_terminations", "typec_sink_advertisement", violations,
            "cc_pins_present_sink_terminations"),
    }


def _resistance_ohms(value):
    match = re.match(r"^([\d.]+)([kM]?)R?$", value)
    if not match:
        return None
    scale = {"": 1.0, "k": 1e3, "M": 1e6}[match.group(2)]
    return float(match.group(1)) * scale


def evaluate_esd_coverage(parameters):
    pin_map = _pin_map()
    net_pins = _net_pins()
    protected = set()
    for reference, part in netlist.PARTS.items():
        spec = parameters["parts"].get(part["mpn"] or "")
        if not spec or "reverse_standoff_v" not in spec:
            continue
        nets = {pin_map.get("%s.1" % reference),
                pin_map.get("%s.2" % reference)}
        if "GND" in nets:
            protected |= {name for name in nets if name and name != "GND"}
    exposed = set()
    for pin_ref in net_pins_of_reference(net_pins, EXPOSED_CONTACT_REFERENCE):
        net_name = pin_map.get(pin_ref)
        if net_name and net_name != "GND":
            exposed.add(net_name)
    exposed.add("BTN_SW")
    violations = sorted(exposed - protected)
    standoff_violations = []
    unevaluated = []
    for reference, part in sorted(netlist.PARTS.items()):
        spec = parameters["parts"].get(part["mpn"] or "")
        if not spec or "reverse_standoff_v" not in spec:
            continue
        standoff = _quantity(spec["reverse_standoff_v"])
        for pin_number in ("1", "2"):
            node = pin_map.get("%s.%s" % (reference, pin_number))
            if node == "GND":
                continue
            span = netlist.RAILS.get(node) or \
                netlist.NODE_VOLTAGE_RANGES.get(node)
            if span is None or not standoff.known:
                unevaluated.append("%s.%s" % (reference, pin_number))
                continue
            if span["max_v"] > standoff.value:
                standoff_violations.append((reference, span["max_v"]))
    standoff_claim = _structural_claim(
        "esd_standoff", "esd_device_not_conducting_in_operation",
        standoff_violations, "standoff_above_rail_maximum")
    if unevaluated:
        standoff_claim = _claim(
            "esd_standoff", "count",
            "esd_device_not_conducting_in_operation", None, None, (),
            _requirement("standoff_above_rail_maximum", "<=", 0.0),
            claim.UNKNOWN, scope_level="board")
    return [{
        "id": "esd_protection_coverage",
        "identity": "exposed_contacts",
        "violations": violations,
        "claim": _structural_claim(
            "exposed_contacts", "esd_protection_present", violations,
            "exposed_contacts_protected_to_ground"),
    }, {
        "id": "esd_standoff_above_rail",
        "identity": "esd_standoff",
        "violations": standoff_violations,
        "unevaluated": unevaluated,
        "claim": standoff_claim,
    }]


def net_pins_of_reference(net_pins, reference):
    prefix = reference + "."
    return [pin_ref for pins in net_pins.values() for pin_ref in pins
            if pin_ref.startswith(prefix)]


def evaluate_probe_access(parameters):
    pin_map = _pin_map()
    test_point_nets = set()
    for reference in netlist.PARTS:
        if reference.startswith("TP"):
            net_name = pin_map.get(reference + ".1")
            if net_name:
                test_point_nets.add(net_name)
    required = set(PROBE_REQUIRED_NETS)
    required |= {name for name in netlist.NETS if name.startswith("LED_CH")}
    violations = sorted(required - test_point_nets)
    # Exactly one part must bridge the input rail to the board rail, whatever
    # kind it is: a link, a diode or a regulator. More than one would mean a
    # parallel supply path that no single measurement characterises, and none
    # would mean the two rails are the same net.
    links = []
    for reference, part in netlist.PARTS.items():
        touched = {net for pin_ref, net in pin_map.items()
                   if pin_ref.split(".", 1)[0] == reference}
        if {"VBUS", "+5V"} <= touched:
            links.append(reference)
    if len(links) != 1:
        violations.append("supply_current_link")
    return {
        "id": "probe_access",
        "identity": "probe_points",
        "violations": violations,
        "series_links": links,
        "claim": _structural_claim(
            "probe_points", "bring_up_probe_access", violations,
            "required_nets_probeable"),
    }


FOOTPRINT_SEARCH_PATHS = (
    os.path.join(REPO_ROOT, "library"),
    FOOTPRINT_ROOT,
)


def _footprint_path(footprint):
    library, _, name = footprint.partition(":")
    for base in FOOTPRINT_SEARCH_PATHS:
        candidate = os.path.join(base, library + ".pretty",
                                 name + ".kicad_mod")
        if os.path.isfile(candidate):
            return candidate
    return os.path.join(FOOTPRINT_ROOT, library + ".pretty",
                        name + ".kicad_mod")
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

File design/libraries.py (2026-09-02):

from __future__ import annotations

import os
import sys

REPO_ROOT = os.path.dirname(os.path.dirname(os.path.abspath(__file__)))
LIBRARY_NAME = "StatusBeacon"
SYMBOL_LIB_PATH = os.path.join(REPO_ROOT, "library", LIBRARY_NAME + ".kicad_sym")
FOOTPRINT_DIR = os.path.join(REPO_ROOT, "library", LIBRARY_NAME + ".pretty")
SYM_LIB_TABLE = os.path.join(REPO_ROOT, "sym-lib-table")
FP_LIB_TABLE = os.path.join(REPO_ROOT, "fp-lib-table")

SYMBOL_LIB_VERSION = "20251024"
FOOTPRINT_VERSION = "20260206"

PY32F003F1XPX_PINS = [
    ("1", "PA2", "bidirectional"),
    ("2", "PA3", "bidirectional"),
    ("3", "PA4", "bidirectional"),
    ("4", "PA5", "bidirectional"),
    ("5", "PA6", "bidirectional"),
    ("6", "PA7", "bidirectional"),
    ("7", "VSS", "power_in"),
    ("8", "PA12", "bidirectional"),
    ("9", "VCC", "power_in"),
    ("10", "PA13-SWD", "bidirectional"),
    ("11", "PA14-SWC", "bidirectional"),
    ("12", "PB5", "bidirectional"),
    ("13", "PB6", "bidirectional"),
    ("14", "PB7", "bidirectional"),
    ("15", "PF4-BOOT0", "bidirectional"),
    ("16", "PF0", "bidirectional"),
    ("17", "PF1", "bidirectional"),
    ("18", "PF2-NRST", "bidirectional"),
    ("19", "PA0", "bidirectional"),
    ("20", "PA1", "bidirectional"),
]

PY32_SYMBOL_NAME = "PY32F003F1xPx"
PY32_DEFAULT_FOOTPRINT = "Package_SO:TSSOP-20_4.4x6.5mm_P0.65mm"
PY32_DATASHEET = "https://download.py32.org/Datasheet/en/PY32F003_Datasheet_Rev1.7.pdf"

X1SON_FOOTPRINT_NAME = "TI_X1SON-2_1.0x0.6mm_P0.65mm"
X1SON_PAD_SIZE_MM = (0.30, 0.50)
X1SON_PAD_PITCH_MM = 0.70
X1SON_BODY_MM = (1.10, 0.70)
X1SON_COURTYARD_MARGIN_MM = 0.15


def _effects():
    return ("\n\t\t\t\t(effects\n\t\t\t\t\t(font\n"
            "\t\t\t\t\t\t(size 1.27 1.27)\n\t\t\t\t\t)\n\t\t\t\t)")


def _symbol_property(key, value, index, hide):
    hidden = "\n\t\t\t(hide yes)" if hide else ""
    return ('\t\t(property "%s" "%s"\n\t\t\t(at 0 %.2f 0)%s\n'
            '\t\t\t(effects\n\t\t\t\t(font\n\t\t\t\t\t(size 1.27 1.27)\n'
            '\t\t\t\t)\n\t\t\t)\n\t\t)\n'
            % (key, value, 17.78 - 2.54 * index, hidden))


def py32_symbol_text():
    left = PY32F003F1XPX_PINS[:10]
    right = PY32F003F1XPX_PINS[10:]
    half = 2.54 * (len(left) - 1) / 2.0
    lines = ['(kicad_symbol_lib',
             '\t(version %s)' % SYMBOL_LIB_VERSION,
             '\t(generator "status-beacon-design-source")',
             '\t(generator_version "10.0")',
             '\t(symbol "%s"' % PY32_SYMBOL_NAME,
             '\t\t(pin_names\n\t\t\t(offset 1.016)\n\t\t)',
             '\t\t(exclude_from_sim no)',
             '\t\t(in_bom yes)',
             '\t\t(on_board yes)']
    lines.append(_symbol_property("Reference", "U", 0, False).rstrip("\n"))
    lines.append(_symbol_property("Value", PY32_SYMBOL_NAME, 1,
                                  False).rstrip("\n"))
    lines.append(_symbol_property("Footprint", PY32_DEFAULT_FOOTPRINT, 2,
                                  True).rstrip("\n"))
    lines.append(_symbol_property("Datasheet", PY32_DATASHEET, 3,
                                  True).rstrip("\n"))
    lines.append('\t\t(symbol "%s_0_1"' % PY32_SYMBOL_NAME)
    lines.append('\t\t\t(rectangle')
    lines.append('\t\t\t\t(start -10.16 %.2f)' % (half + 2.54))
    lines.append('\t\t\t\t(end 10.16 %.2f)' % (-half - 2.54))
    lines.append('\t\t\t\t(stroke\n\t\t\t\t\t(width 0.254)\n'
                 '\t\t\t\t\t(type default)\n\t\t\t\t)')
    lines.append('\t\t\t\t(fill\n\t\t\t\t\t(type background)\n\t\t\t\t)')
    lines.append('\t\t\t)')
    lines.append('\t\t)')
    lines.append('\t\t(symbol "%s_1_1"' % PY32_SYMBOL_NAME)
    for index, (number, name, kind) in enumerate(left):
        y = half - 2.54 * index
        lines.append(_pin_text(kind, -12.7, y, 0, name, number))
    for index, (number, name, kind) in enumerate(reversed(right)):
        y = half - 2.54 * index
        lines.append(_pin_text(kind, 12.7, y, 180, name, number))
    lines.append('\t\t)')
    lines.append('\t)')
    lines.append(tvs_symbol_text())
    lines.append(ldo_symbol_text())
    lines.append(')')
    return "\n".join(lines) + "\n"


def _pin_text(kind, x, y, angle, name, number):
    return ('\t\t\t(pin %s line\n\t\t\t\t(at %.2f %.2f %d)\n'
            '\t\t\t\t(length 2.54)\n'
            '\t\t\t\t(name "%s"%s\n\t\t\t\t)\n'
            '\t\t\t\t(number "%s"%s\n\t\t\t\t)\n\t\t\t)'
            % (kind, x, y, angle, name, _effects(), number, _effects()))


def x1son_footprint_text():
    width, height = X1SON_PAD_SIZE_MM
    offset = X1SON_PAD_PITCH_MM / 2.0
    body_x, body_y = (value / 2.0 for value in X1SON_BODY_MM)
    court_x = body_x + X1SON_COURTYARD_MARGIN_MM
    court_y = body_y + X1SON_COURTYARD_MARGIN_MM
    pads = []
    for number, sign in (("1", -1.0), ("2", 1.0)):
        pads.append(
            '\t(pad "%s" smd roundrect\n\t\t(at %.3f 0)\n'
            '\t\t(size %.3f %.3f)\n\t\t(layers "F.Cu" "F.Paste" "F.Mask")\n'
            '\t\t(roundrect_rratio 0.1667)\n\t)'
            % (number, sign * offset, width, height))
    outline = []
    for layer, half_x, half_y, thickness in (
            ("F.CrtYd", court_x, court_y, 0.05),
            ("F.Fab", body_x, body_y, 0.1)):
        outline.append(
            '\t(fp_rect\n\t\t(start %.3f %.3f)\n\t\t(end %.3f %.3f)\n'
            '\t\t(stroke\n\t\t\t(width %.2f)\n\t\t\t(type default)\n\t\t)\n'
            '\t\t(fill none)\n\t\t(layer "%s")\n\t)'
            % (-half_x, -half_y, half_x, half_y, thickness, layer))
    return "\n".join([
        '(footprint "%s"' % X1SON_FOOTPRINT_NAME,
        '\t(version %s)' % FOOTPRINT_VERSION,
        '\t(generator "status-beacon-design-source")',
        '\t(generator_version "10.0")',
        '\t(layer "F.Cu")',
        '\t(descr "TI DPY0002A land pattern, SLLSEB1G figure 4224561/C")',
        '\t(tags "X1SON DPY TVS")',
        '\t(attr smd)',
        '\t(property "Reference" "REF**"\n\t\t(at 0 -1.2 0)\n'
        '\t\t(layer "F.SilkS")\n\t\t(uuid "00000000-0000-0000-0000-'
        '000000000001")\n\t\t(effects\n\t\t\t(font\n\t\t\t\t(size 0.6 0.6)\n'
        '\t\t\t\t(thickness 0.1)\n\t\t\t)\n\t\t)\n\t)',
        '\t(property "Value" "%s"\n\t\t(at 0 1.2 0)\n'
        '\t\t(layer "F.Fab")\n\t\t(uuid "00000000-0000-0000-0000-'
        '000000000002")\n\t\t(effects\n\t\t\t(font\n\t\t\t\t(size 0.6 0.6)\n'
        '\t\t\t\t(thickness 0.1)\n\t\t\t)\n\t\t)\n\t)' % X1SON_FOOTPRINT_NAME,
    ] + outline + pads + [')']) + "\n"
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

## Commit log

2026-08-30 Seed benchmark board 01/32 from its supplied brief
    PCBA_StatusBeacon is one of thirty-two boards in the PCBA_AutoDesignAndTest
    benchmark. This commit establishes the repository and nothing else:
    the board is not designed, and its absence is the intended state.
    BRIEF.md is the supplied brief, preserved byte for byte and
    authoritative. board/requirements.json splits it into fixed_requirements
    -- each carrying the verbatim brief text that substantiates it, bound to
    the SHA-256 of the brief's bytes -- and open_decisions, which are the
    design agent's to make and to record as choices. Promoting a decision
    into a requirement is the failure the split exists to prevent.
    docs/architecture.md is a wo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
2026-08-30 Stop the scaffold claiming a check it does not perform
    An external review of the pushed benchmark found this repository asserting
    three things about itself that were not true as shipped.
    board/manifest.template.json said running the validator against it "will
    fail on the missing source". It does not: `run.py validate
    board/manifest.template.json` exits 0 and prints ACCEPTED, with all 36 gates
    NOT_APPLICABLE and no gate reading sources.pcb, so the absent board file is
    never noticed. The template now says exactly that, under verdict_warning,
    and docs/status.md and CLAUDE.md carry the same warning where a reader and
    an agent will actually meet it. The toolkit is behaving as designed - a gate
    w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
2026-08-30 Remove the claim-audit skill, and the instructions that called it
    Requested. .claude/skills/claim-audit/ is deleted, and with it every
    reference: CLAUDE.md's publishing discipline no longer names it, and the
    README layout table no longer advertises it.
    accountability-review kept calling it at step 3, which would have left the
    surviving skill invoking one that is not in the clone - the same
    dangling-instruction defect that put these skills in the repository in the
    first place. That step now states the claim-binding work directly: scan the
    drafts for claim-bearing words, and bind each to an artifact recomputed on
    the spot rather than to the process that produced it. The discipline is
    unchange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
2026-08-30 Finish removing claim-audit: the last prose reference to it
    accountability-review still explained itself with "that is why the claim
    audit runs first". Nothing runs first any more - the claim binding is step 3
    of this skill, and it runs before the review package is assembled, not
    before the review. The sentence now says that.
    Removing a skill is not done when its file is gone. It is done when nothing
    left in the repository tells a reader to go and find it.
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2026-09-02 Close the release terminus: build, validate and commit fabrication outputs
    Declare the artifact, archive, assembly, release-generation, reports and
    release-profile blocks the build and release gates read, carry LCSC into the
    schematic so the BOM the assembly house reads comes from the design authority,
    and add the geometry tolerances the export-parity gates bound their comparisons
    with. 18 gates pass, 15 report NOT_APPLICABLE with a reason.
    [bom.csv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]
2026-09-02 Close loop steps 8, 10, 11, 18 and 19: fab process, extraction, simulation
    Select the JLCPCB process against declared fabrication requirements, take the
    finished external copper thickness from the approved catalog rather than the
    nominal foil weight, and extract the LED data path's DC resistance from the
    routed copper into a simulation model bound to this exact board.
    Four scenarios, all executed at validate time: rail droop when the whole ring
    turns on (4.704 V minimum against the LED's 4.5 V characterised floor), button
    release detection at the firmware deadline, and the shortest protocol high time
    driven over ideal interconnect and over the extracted copper. The extracted
    resistance is a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
    [status_beacon-B_Cu.gbr, status_beacon-B_Mask.gbr, status_beacon-B_Silkscreen.gbr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]
2026-09-02 Extract the copper model at validate time instead of freezing it
    The board no longer generates sim/models.json. The manifest names the path
    and a stable alias, and the toolkit traces the copper during validation, so
    there is no earlier file that could have gone out of date with the board.
    The measured identity, which embeds the board digest, stays in the model's
    derivation.
    [status_beacon-B_Cu.gbr, status_beacon-B_Mask.gbr, status_beacon-B_Silkscreen.gbr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]
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2026-09-02 Declare the connector contracts and the via mask design target
    Both connectors now have a release gate over their pin map, position count,
    mounting side, gender and population state, rather than only the board-side
    rules. The via annulus-to-mask-opening design target is the board's own
    0.15 mm minimum clearance; all 49 vias clear it. No process limit is
    declared, because the approved JLCPCB catalog carries solder-mask thicknesses
    and no lateral via-to-opening figure, and that number will not be invented.
    23 gates pass.
    [status_beacon-B_Cu.gbr, status_beacon-B_Mask.gbr, status_beacon-B_Silkscreen.gbr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]
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2026-09-02 Freeze the fabricator-derived physical inputs beside the requirements
    design/physical.py resolves finished external copper and board thickness
    from the approved JLCPCB catalog into parameter records carrying their
    source type and the catalog's digest, and verifies a committed set still
    agrees with it. The simulation gate reads those records instead of reaching
    into the fabricator package.
    [status_beacon-B_Cu.gbr, status_beacon-B_Mask.gbr, status_beacon-B_Silkscreen.gbr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]
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2026-09-02 Take the LED input capacitance from the datasheet, not an assumption
    The WS2812B datasheet states input capacity CI = 15 pF; the data-edge
    scenario had assumed 10 pF. Recorded in components/parameters.json with a
    direct basis and read from there, so the electrically-short bound the
    reference-gap rule derives now rests on evidence: 15.25 mm, against the
    10.0 mm the manifest declares.
    [status_beacon-B_Cu.gbr, status_beacon-B_Mask.gbr, status_beacon-B_Silkscreen.gbr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]
2026-09-02 Series Schottky, and move off the discontinued LED
    R3 (0R) becomes D17, a 1N5819WS Schottky in the VBUS to +5V path: a JLCPCB
    basic part at $0.0116 with 1 A rating and Vf <= 0.60 V at 1 A. D1-D12 move
    from WS2812B-B/T, which JLCPCB flags discontinued, to WS2812B-V5/W. The MCU
    is unchanged: PY32F003F18P6TU is already the x6 variant, 1.7-5.5 V, so it
    spans the whole post-diode rail with 2.65 V to spare below it.
    The declared rails are now what the parts and the source actually permit.
    VBUS is 4.75-5.5 V, which is vSafe5V rather than a narrower claim, so
    usb_source_range_coverage passes on the truth instead of failing on a
    declaration that did not cover the source. +5V runs from 4.15 V - the s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
    [bom.csv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]
2026-09-02 Regulate the rail: ME6211C50 LDO replaces the series Schottky
    D17 and its 2 mV of margin are gone. U2 is an ME6211C50M5G-N in SOT-23-5,
    with C17 as its input capacitor on VBUS; C1 stays on the output. The rail is
    now the regulator's specified band rather than a source minus a drop nobody
    guarantees: 4.05 to 5.05 V, against the WS2812B-V5's 3.70 to 5.30 V absolute
    range. High margin +250 mV comes off the datasheet's +/-1% output tolerance;
    low margin +350 mV from its dropout extrapolated to the declared port budget
    and derated for temperature.
    That is the whole point of the change. The twelve LED absolute-maximum checks
    no longer report UNKNOWN because a lower bound could not decide them; th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
    [bom.csv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]
2026-09-02 Thermal analysis: the domain section 24 asks for, and what it found
    design/thermal.py computes what each part dissipates from the frozen
    parameters and the netlist, then the board's rise over ambient from natural
    convection and radiation on both faces of the outline, solved by iteration
    because both coefficients depend on the rise they are used to find. Five
    rules in design/rules.py evaluate the result against the ratings.
    The finding is the regulator, not the LEDs. At full brightness it dissipates
    199 mW; its package rating derates to 172 mW at the board temperature that
    brightness produces, so full brightness is not thermally valid at the
    declared ambient - the estimate supports only 25.2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
    [status_beacon-B_Cu.gbr, status_beacon-B_Mask.gbr, status_beacon-B_Silkscreen.gbr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]
2026-09-02 Refresh the frozen fabrication inputs against the current catalog
    The toolkit's JLCPCB catalog gained a dielectric constant stated for a
    two-layer laminate, moving its content digest. This board's frozen copper
    records still claimed the old one, so extract.verify_approved_parameter
    refused them - correctly: a record whose digest no longer matches is a
    claim about a catalog that is no longer there, and two tests said so.
    Every engineering value is unchanged; only the digest moved. Selection is
    regenerated alongside, and now records that no two-layer construction is
    published while one can be composed from stated values.
    [status_beacon-B_Cu.gbr, status_beacon-B_Mask.gbr, status_beacon-B_Silkscreen.gbr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]
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2026-09-03 Rebind the release to the toolkit commit that produced it
    The toolkit advanced by four commits during this work, adding two-layer
    dielectric composition to the JLCPCB profile. The source closure binds the
    implementation identity, so the committed reports stopped describing the
    validator that would judge them. Regenerated and revalidated against
    3516aa6: 23 gates pass, 13 report NOT_APPLICABLE, 72 tests pass.
    [status_beacon-B_Cu.gbr, status_beacon-B_Mask.gbr, status_beacon-B_Silkscreen.gbr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]
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2026-09-03 Retire the hand-written routing acceptance list
    The toolkit's design gate class replaces it: candidate acceptance now
    selects --only=design, expanded by the toolkit, so the set cannot rot
    as gates are added. The list leaves the manifest and the routing script that read it, and the
    release is regenerated under toolkit b441685, which also closes the
    review findings on the phase 0 seams: 23 gates pass, 13 report
    NOT_APPLICABLE.
    [status_beacon-B_Cu.gbr, status_beacon-B_Mask.gbr, status_beacon-B_Silkscreen.gbr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]
2026-09-03 Close the adversarial findings that reached this board
    The unread keys the manifest carried are gone: tolerance_seconds is
    deleted, contact_semantics becomes the note annotation it always was,
    and the schema now refuses both by name. The routing acceptance
    selection regains ROUTE.PROVENANCE - the loop writes the record before
    judging, so record-board agreement is judged per candidate as it was
    under the hand-written list, and the acceptance tests now assert the floor of gates the loop depends on as well as the artifact-gate exclusions. Regenerated and revalidated under
    toolkit a0f53eb: 23 gates pass, 13 report NOT_APPLICABLE.
    [status_beacon-B_Cu.gbr, status_beacon-B_Mask.gbr, status_beacon-B_Silkscreen.gbr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]
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2026-09-03 Rebind the release to toolkit 7f51066
    The panel-fix round widened the source closure to every staged design
    input and hardened the verdict binding, so the fabrication outputs and
    the recorded verdict are regenerated under the new toolkit. The
    transient .pcbqa-hold-* lock file is ignored.
    The board's .kicad_prl is a design input the toolkit stages for every
    check, so it is now tracked rather than gitignored - the source closure
    covers it and release readiness requires it in the tag.
    [status_beacon-B_Cu.gbr, status_beacon-B_Mask.gbr, status_beacon-B_Silkscreen.gbr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]
2026-09-04 Delete the routing loop, declare the search, rebind to toolkit bd0ad78
    The private search loop, tidy passes and record writer move to the
    toolkit's run.py route, driven by the routing.search and
    routing.transforms declarations. The declaration is reserved-complement
    (the toolkit requires every zone-owning net in scope or reserved, and
    the GND pour must be reserved); route --check proves the resolved scope
    equals the recorded run's exactly. The old snap-to-via used a 0.25 mm
    reach; the toolkit's snap is annulus-bounded by design - a wider reach
    once moved copper past a clearance boundary its check had already
    accepted. layout.write() now saves through the toolkit's
    project-preserving save. Th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
    [status_beacon-B_Cu.gbr, status_beacon-B_Mask.gbr, status_beacon-B_Silkscreen.gbr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]
2026-09-04 Declare the placement gates; delete the route.py invoker
    placement.courtyard and placement.edge_clearance (0.1 mm, courtyard
    basis) are declared - this board's parts sit clear of its outline,
    so it can promise both, and the search preflights them before the
    first router attempt. design/route.py is deleted per the plan;
    `run.py route` is the entry point. Fabrication binding refreshed
    under the reviewed toolkit.
2026-09-04 Refresh the fabrication binding under the reviewed toolkit
    The toolkit's third review round hardened adoption durability, record
    bindings and their enforcement; nothing in this board's own sources
    changed. Rebuilt and revalidated so the committed verdict and closure
    name the reviewed toolkit state.
2026-09-05 Refresh the fabrication binding under the reviewed toolkit
    The toolkit's fourth review round pinned the routing judgment to its
    recorded policy at the read site, fixed the router-summary shape the
    reconciliation reads, and extended post-adoption enforcement to the
    manifest digest and recorded plan; nothing in this board's own sources
    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
2026-09-05 Refresh the fabrication binding under the reviewed toolkit
    The toolkit's fifth review round closed its last blocker: with a
    recorded binding declared, every acceptance gate now reads the
    verified staged design instead of live pathnames. Nothing in this
    board's own sources changed. Rebuilt and revalidated so the committed
    verdict and closure name the reviewed toolkit state.
2026-09-05 Refresh the fabrication binding under the reviewed toolkit
    The toolkit's sixth review round bound every auxiliary file the
    routing acceptance gates consume - stackup supplements, contract
    documentation, simulation records - into the routing record, enforced
    at adoption, check, provenance and replay; nothing in this board's
    own sources changed. Rebuilt and revalidated so the committed verdict
    and closure name the reviewed toolkit state.
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2026-09-05 Refresh the fabrication binding under the committed Phase 2 toolkit
    The toolkit's evidence-governance commit is a source-closure member,
    so the committed artifacts and verdict re-bind to it. Nothing in this
    board's own sources changed in this commit.
2026-09-05 Refresh the fabrication binding under the review-fixed Phase 2 toolkit
    The first adversarial review round hardened the evidence machinery
    (derived documents rebound, staged generators, advisory surfaced);
    nothing in this board's own sources changed in this commit.
2026-09-05 Adopt the round-3 corrections: the claim document joins the closure
    The claim document the verdict rests on joins the source closure, so
    a release tag carries it and its movement is a named staleness. The
    claims generator declaration is now mandatory toolkit-side
    (CLAIM.MATRIX refuses an unlisted document), which this board already
    satisfied.
2026-09-05 Refresh the fabrication binding: round-3 verdict rendering
    The toolkit's open-item rendering commit is a closure member; this
    board's committed verdict re-binds to it. No board sources changed.
2026-09-05 Refresh the fabrication binding: fourth-round evidence fixes
    The toolkit now lists register methods still required that no
    dependency owns as open items in the policy state - a passing claim
    establishes the number, never the separately declared method - and the
    refreshed validation record carries whatever this board honestly owes.
2026-09-05 State the dropout citation's operating point
    PROV.DEVICE_PARAMETERS now judges validity from the operating point the
    design presents rather than a name token: the citation carries
    parameters[].operating and the claim carries exactly the statements
    extrapolation_assumptions writes for it. The helper also corrected this
    board's prose where a hand-written load figure had drifted from the
    computed maximum. Binding refreshed against the fifth-round toolkit.
    [rules.py]
2026-09-05 Refresh the fabrication binding: sixth-round toolkit
    PROV.DEVICE_PARAMETERS now judges applicability from the citation
    rather than from the presence of a validity range - a record with no
    stated range has no supported range. Nothing on this board changes
    beyond the closure; its citations already state their operating points.
2026-09-05 Re-freeze against the advanced fabricator catalogue
    Phase 3.1 published seven more capabilities from the SAME frozen
    evidence - hole plating thickness, the PTH annular ring, and the
    soldermask process set - so the approved catalogue's normalized digest
    moved from 953f02ea to e504b0de. Every physical input this board froze
    records the catalogue state it was resolved from, so those records were
    re-frozen against the current one.
    Nothing this board selects changed: the process selection came back
    byte-identical apart from the digest, and no physical value moved. The
    new capabilities describe plating and soldermask, which this board's
    selection does not turn on.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
2026-09-05 Decide, on the record, about the five domains Phase 3 added
    Phase 3 implements thermal, current capacity, power integrity,
    differential pair and reference continuity as evidence domains, so
    saying nothing about them is no longer a neutral act: silence lands the
    policy state on requires-additional-evidence.
    This board declines all five, each with a reason true of THIS board -
    what it does instead, or why the domain does not describe it. It cannot
    honestly declare them: declaring one means authoring a capacity basis, a
    set of thermal-resistance records or a rail mesh, and inventing any of
    that is precisely the fabrication this toolkit exists to prevent. Where
    the board already answers the que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
2026-09-05 Refresh the fabrication binding against the reviewed Phase 3 toolkit
    The toolkit is a source-closure member, so four rounds of adversarial
    review over Phase 3 mean the committed reports and the validation record
    are re-made against the code that now exists. Nothing about this board
    changed.
2026-09-06 Rebuild the artifacts against the fifth-review toolkit
    No verdict moves and no gate changes status: the round closed defects in
    the current, PDN, coverage and arc paths, and what this board exercises
    of them it already exercised correctly. The artifacts are refreshed so
    the recorded run names the toolkit commit that produced it rather than
    one four fixes behind.
2026-09-06 Cite the via-mask process limit, and leave standing the failure it exposes
    Declaring via_mask.process enables two gates this board never ran. One
    passes: VIA.MASK_CLEARANCE_PROCESS clears all 51 vias against JLCPCB's
    published 0.09 mm soldermask-opening clearance, cited from the catalogue
    state fab/selection.json already resolved the fabrication against rather
    than restated by hand.
    The other, VIA.NATIVE_GERBER_AGREEMENT, fails with 44 disagreements, and
    they are spurious. The toolkit's _native_opening_polygon keys its lookup
    on a pad's number, which is not unique: J1 carries four pads named SH and
    J2 three unnumbered ones, so nine back-side mask openings collapse onto
    three and every via n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
2026-09-06 The two catalog-cited via gates run and pass; the artifacts follow
    This board declared via_mask.process.limit_from_catalog and left
    standing the VIA.NATIVE_GERBER_AGREEMENT failure it exposed - 6 of 9
    back-side openings vanished into a label-keyed table (four pads named
    SH, three named ''), and every via near a lost opening was compared
    against the survivor. The toolkit now keys mask openings by the pad's
    KIID, and both gates run and PASS on this board: all 51 vias match the
    export object by object. The recorded validation moves
    NOT_APPLICABLE -> PASS on both, and no other verdict changes.
2026-09-06 Rebuild the artifacts against the review-response toolkit
    No verdict moves and no gate changes status. The round closed the
    island-barrel channel in the PDN mesh, scoped the thermal copper
    ceiling to a named pad, and corrected two verdict texts; what this
    board exercises of them it already exercised correctly, and the refresh
    binds the record to the toolkit commit that produced it.
2026-09-06 Rebuild the artifacts against the second-pass toolkit
    No verdict moves and no gate changes status. The pass closed the
    untested through-hole half of the island-barrel filter and composed
    every standing THERMAL.DERATING problem into its verdict; what this
    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
2026-09-06 Rebuild the artifacts against the fragility-knob toolkit
    No verdict moves and no gate changes status. The toolkit pins
    KICAD_PLANE_FRAGILITY_COST=0 for every FUTURE owned search - KiCad's
    zone filler is a thread race the field inherited, core pinning
    measurably does not close it, and disabling the field is deterministic
    by construction. This board's adopted route and record are untouched:
    the knob binds searches, not validations, and a replay of the old
    record now refuses the environment check as it should. The refresh
    binds the artifacts to the toolkit commit that produced them.
2026-09-07 Rebuild the artifacts against the fill-oracle-account toolkit
    No verdict moves and no gate changes status. The wrapper now refuses a
    router summary that cannot account for which pour geometry its
    fragility field used; this board's adopted route and record are
    untouched, and the refresh binds the artifacts to the toolkit commit
    that produced them.
2026-09-07 Rebuild the artifacts against the upstream-merged toolkit
    No verdict moves and no gate changes status. The pinned router advanced
    through 254 upstream commits (grid_router v0.22.0, the #831 fill-oracle
    account the wrapper now reads, the --clearance semantics split); this
    board's adopted route and record are untouched, future searches inherit
    the new semantics, and the refresh binds the artifacts to the toolkit
    commit that produced them.
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2026-09-11 Decide the two domains Phase 4 added, and rebuild under KiCad 10.0.6
    Phase 4 gave BOM.LIFECYCLE and the ASM/DFA gates their own evidence
    domains, and a board that says nothing about a domain has decided
    nothing about it. This board's policy state was
    requires-additional-evidence with exactly two reasons on it - lifecycle
    and assembly_process, neither declared nor declined. Both are now
    declined on the record, and the board is fabrication-ready again.
    assembly_process was measured before it was declined, not reasoned
    about. Declaring assembly.process with the profile BRIEF.md already
    fixes - one reflow pass, single-side placement - produces 30 declaration
    problems: 18 placed footprints carry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
    [status_beacon-B_Cu.gbr, status_beacon-B_Mask.gbr, status_beacon-B_Silkscreen.gbr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]
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
